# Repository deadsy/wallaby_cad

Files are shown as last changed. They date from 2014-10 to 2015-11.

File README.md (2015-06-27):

# wallaby_cad

CAD files for the Wallaby Engine

## Scaling

These CAD files are the size of the original plans.
I wanted a larger engine and so scaled each linear dimension by 1.25

Engine Build = 1.25
Pattern Scaling = (1.25/0.98) = 1.276

Carburetor Build = sqrt(1.25^3) = 1.398
Pattern Scaling = (1.398/0.98) = 1.426

 * Al casting shrinkage = 0.98
 * Fuel volume requirements are a function of engine volume while carburetor delivery capability is a function of bore area.

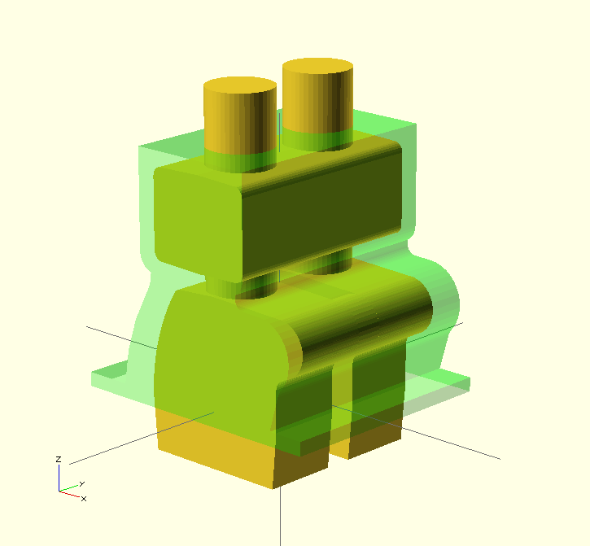
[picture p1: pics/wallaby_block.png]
Wallaby Engine Block with Core


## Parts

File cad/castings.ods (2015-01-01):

Description | CAD | Pattern | Casting | Material | Needed | Made | Notes
Engine Sump | Done | Done | Done | Al | 1 | 2
Engine Block | Done | Done | Done | Al | 1 | 2
Timing Cover | Done | Done | Done | Al | 1 | 2
Cylinder Head | Partial |  |  | Al | 1 | 0
Cylinder Head Cover | Done | Done | Done | Al | 1 | 2
Bearing Cap | Done | Done | Done | Al | 1 | 2 | 3 cut from each casting
Conrod | Done | Done |  | Bronze | 2 | 0
Piston | Done |  |  | Al | 2 | 0
Balance Weight | Done | Done | Partial | Bronze | 2 | 1 | 2 cut from each casting
Valve Rocker Bearing | Done | Done |  | Al | 1 | 0
Oil Pump Body | Done | Done | Partial | Brass | 1 | 0
Flywheel | Done | Done | Done | Brass | 1 | 2
Inlet Stub | Done |  |  | Al | 1 | 0
Carburettor Body |  |  |  | Al | 1 | 0
Float Chamber |  |  |  | Al | 1 | 0

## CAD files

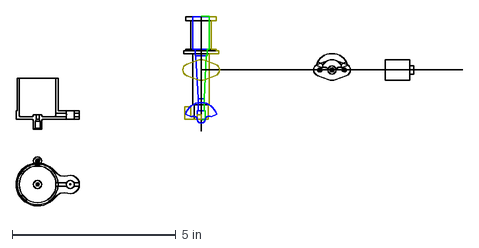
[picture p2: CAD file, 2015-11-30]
cad/carburetor.dxf
13.7 x 5.85 in

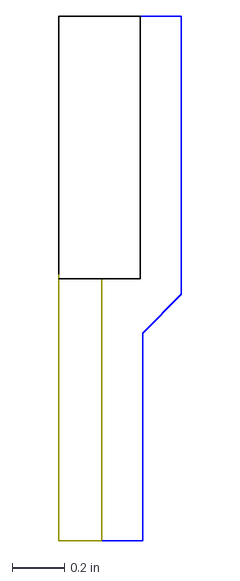
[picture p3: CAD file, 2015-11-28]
cad/sparkplug.dxf
0.469 x 2.00 in

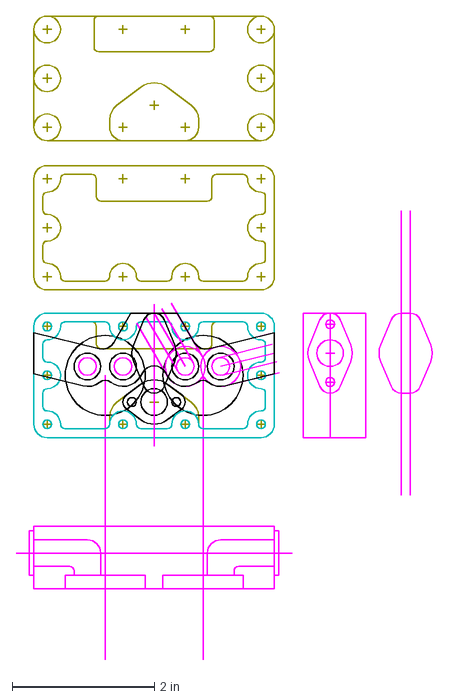
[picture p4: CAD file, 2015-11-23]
cad/head_cover.dxf
5.86 x 9.05 in

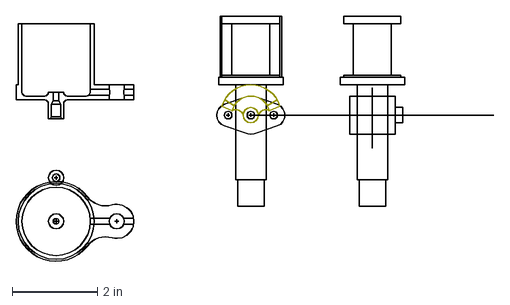
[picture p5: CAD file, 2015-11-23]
cad/carburetor_scaled.dxf
11.2 x 5.83 in

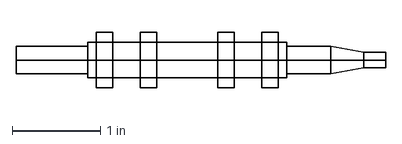
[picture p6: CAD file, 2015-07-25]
cad/camshaft.dxf
4.19 x 0.625 in

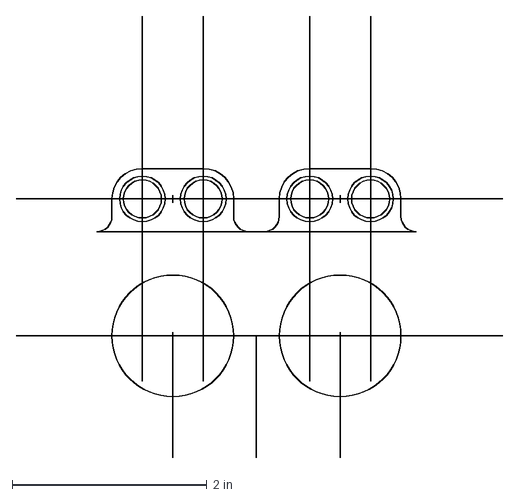
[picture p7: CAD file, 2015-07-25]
cad/bore_spacing_scaled.dxf
5.00 x 4.53 in

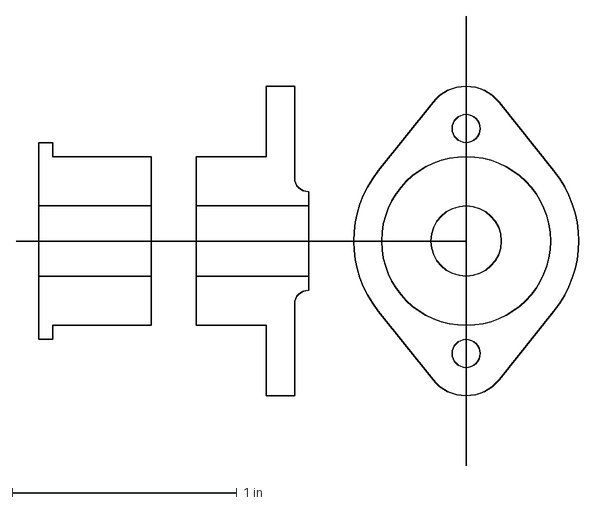
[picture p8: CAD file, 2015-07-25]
cad/cam_bearings.dxf
2.54 x 2.00 in

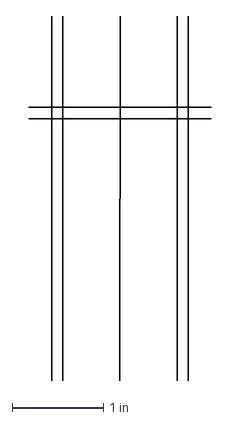
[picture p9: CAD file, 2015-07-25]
cad/cylinder_liner.dxf
2.00 x 4.00 in

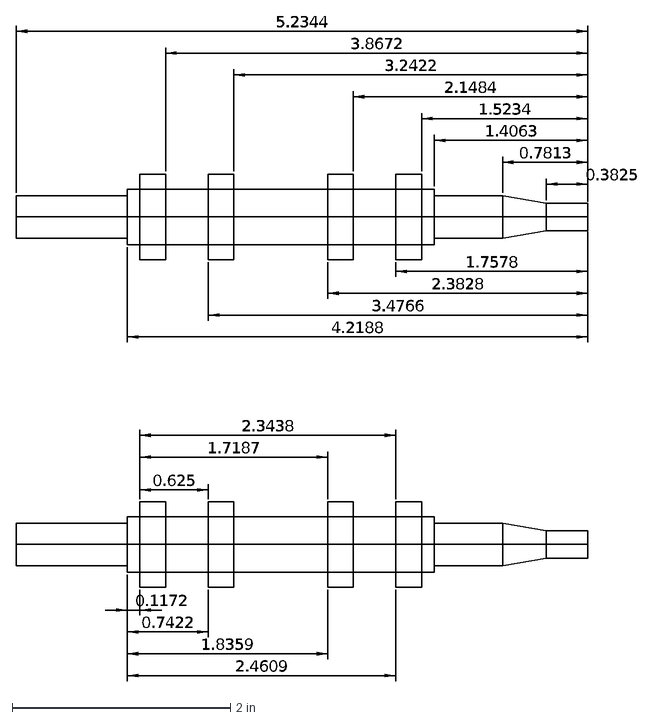
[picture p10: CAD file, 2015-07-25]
cad/camshaft_scaled.dxf
0.7813
1.4063
1.5234
2.1484
3.2422
3.8672
5.2344
1.7578
2.3828
3.4766
4.2188
0.1172
0.7422
1.8359
2.4609
0.625
1.7187
2.3438
0.3825

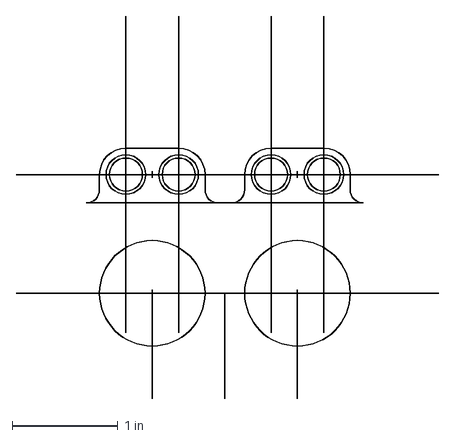
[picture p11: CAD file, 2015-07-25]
cad/bore_spacing.dxf
4.00 x 3.62 in

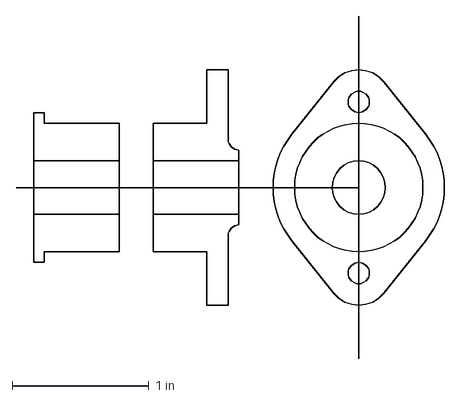
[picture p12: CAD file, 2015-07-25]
cad/cam_bearings_scaled.dxf
3.17 x 2.50 in

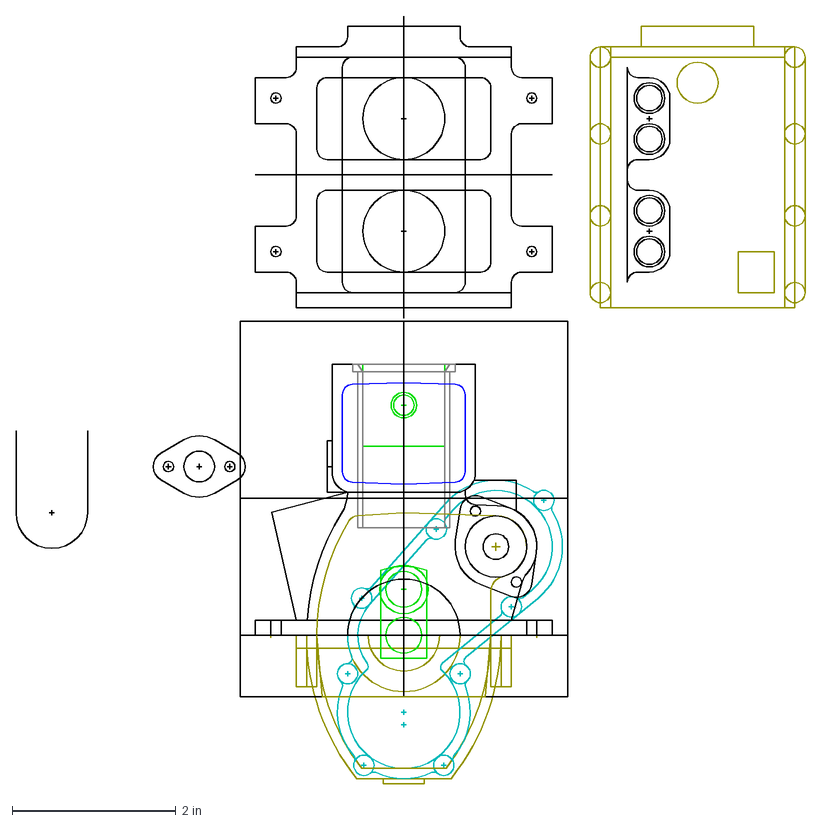
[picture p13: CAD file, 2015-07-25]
cad/engine_body.dxf
9.64 x 9.38 in

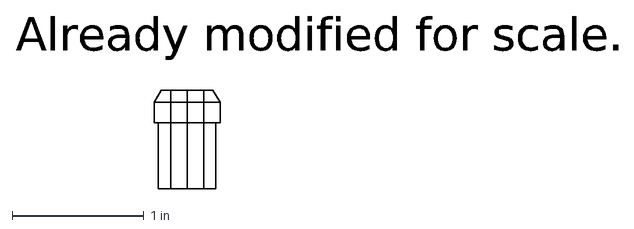
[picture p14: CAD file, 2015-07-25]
cad/lifters.dxf
Already modified for scale.

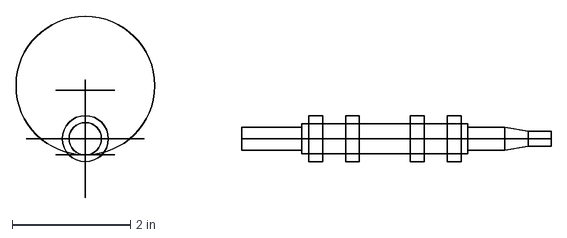
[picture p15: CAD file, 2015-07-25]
cad/cam_jig.dxf
9.06 x 3.07 in

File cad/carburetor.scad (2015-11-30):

//------------------------------------------------------------------


//------------------------------------------------------------------

casting = false;

//------------------------------------------------------------------
// tweak a length to avoid rendering issues when diff-ed surfaces
// align with each other.

tweak = 0.001;

//------------------------------------------------------------------
// control the number of facets on cylinders

_accuracy = 0.001;
function fn(r) = 180 / acos(1 - (_accuracy / r));

//------------------------------------------------------------------

module carb_body() {
  rotate_extrude($fn = 64)
  import(file = "carburetor.dxf", layer = "body_profile",  $fn = fn(0.1));
}

module carb_body_bore() {
  rotate_extrude($fn = 64)
  import(file = "carburetor.dxf", layer = "body_bore_profile",  $fn = fn(0.1));
}

hh_r = (1/16)/2;
hh_l = (1/2);
hh_pcr = (13/16)/2;
head_z = 3 + (1/8);

module head_holes() {
  for (theta = [30,90,150,210,270,330]) {
    rotate([0,0,theta]) {
      translate([hh_pcr,0,-hh_l/2 + head_z]) {
        cylinder(h = hh_l, r = hh_r, $fn = fn(hh_r));
      }
    }
  }
}

//------------------------------------------------------------------

tb_w = 3/4;

module throttle_body() {
  rotate([90,0,0]) {
    translate([0,0,-tb_w/2]) {
      linear_extrude(height = tb_w)
      import(file = "carburetor.dxf", layer = "throttle_body_profile",  $fn = fn(0.1));
    }
  }
}

tbb_r = (1/2)/2;
tbb_l = 5/8;
tbb_z = 1 + (1/2);

module tb_bore() {
  translate([0,tb_w/2 + tweak,tbb_z]) {
    rotate([90,0,0]) {
      cylinder(h = tbb_l, r = tbb_r, $fn = fn(tbb_r));
    }
  }
}

tbh_r = (1/8)/2;
tbh_l = 2;

module tb_holes() {
  for (ofs = [-(3/8), 0, (3/8)]) {
    translate([ofs,0,tbb_z]) {
      rotate([90,0,0]) {
        translate([0,0,-tbh_l/2]) {
          cylinder(h = tbh_l, r = tbh_r, $fn = fn(tbh_r));
        }
      }
    }
  }
}

tp_h = 1;

module throttle_plate() {
  translate([0,-tb_w/2 + tweak,tbb_z]) {
    rotate([90,0,0]) {
      intersection() {
        translate([0,0,-tp_h/2]) {
          linear_extrude(height=tp_h)
          import(file = "carburetor.dxf", layer = "throttle_plate_pattern",  $fn = fn(0.1));
        }
        rotate_extrude($fn = 64)
        import(file = "carburetor.dxf", layer = "throttle_plate_profile",  $fn = fn(0.1));
      }
    }
  }
}

//------------------------------------------------------------------
// airholes

aht_r = (5/32)/2;
aht_l = 2;
aht_z = (3.125 - (7/16));

module air_holes_top() {
  translate([0,0,aht_z]) {
    for (theta= [0,60,120]) {
      rotate([0,0,theta]) {
        rotate([90,0,0]) {
          translate([0,0,-aht_l/2]) {
            cylinder(h = aht_l, r = aht_r, $fn = fn(aht_r));
          }
        }
      }
    }
  }
}

ahb_r = (1/8)/2;
ahb_l = 2;
ahb_z = (5/16);

module air_holes_bottom() {
  translate([0,0,ahb_z]) {
    for (theta= [0,90]) {
      rotate([0,0,theta]) {
        rotate([90,0,0]) {
          translate([0,0,-ahb_l/2]) {
            cylinder(h = ahb_l, r = ahb_r, $fn = fn(ahb_r));
          }
        }
      }
    }
  }
}

//------------------------------------------------------------------

module base_add() {
  carb_body();
  throttle_body();
  throttle_plate();
}

module base_sub() {
  if (casting) {
  } else {
    carb_body_bore();
    air_holes_top();
    air_holes_bottom();
    tb_bore();
    tb_holes();
    head_holes();
  }
}

module base_model() {
  difference() {
    base_add();
    base_sub();
  }
}

//------------------------------------------------------------------

module model() {
  base_model();
}

model();

//------------------------------------------------------------------

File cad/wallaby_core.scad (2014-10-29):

//------------------------------------------------------------------
/*

Wallaby Engine Block Core

*/
//------------------------------------------------------------------
// scaling

_desired_scale = 1.25;
_al_shrink = 0.98;
_scale = _desired_scale / _al_shrink;

//------------------------------------------------------------------
// control the number of facets on cylinders

_accuracy = 0.001;
function fn(r) = 180 / acos(1 - (_accuracy / r));

//------------------------------------------------------------------
// cylinder cores

// unscaled sizes: core = 0.875, cylinder bore = 1.000, liner bore = 1.125
// scaled sizes: core = 1.125, cylinder bore = 1.25, liner bore = 1.406
// So: In the scaled engine we have core size that matches a standard dowel and > 1/4"
// of machining tolerance on the liner bore diameter.

cylinder_d = (1 + (1/8)) / _scale; // diameter
cylinder_h = (3 + (5/16)); // height
core_print_h = 3/4;
c2c_d = (1 + (3/8));

cylinder_r = cylinder_d / 2.0;

module cylinder_core(d) {
	translate([0, d, 0]) {
		cylinder(h = cylinder_h + core_print_h, r = cylinder_r, $fn = fn(cylinder_r));
	}
}

module cylinder_cores() {
	cylinder_core(-c2c_d / 2.0);
	cylinder_core(c2c_d / 2.0);
}

//------------------------------------------------------------------
// camshaft core

camshaft_d = (3/4); // diameter
camshaft_l = 2 + (3/8); // length
camshaft_dx = (1 + (1/8)); // x-displacement
camshaft_dz = 1.084; // z-displacement

camshaft_r = camshaft_d / 2.0;

module camshaft_core() {
	translate([camshaft_dx, 0, camshaft_dz]) {
		rotate([90, 0, 0]) {
			cylinder(h = camshaft_l, r = camshaft_r, center = true, $fn = fn(camshaft_r));
		}
	}
}

//------------------------------------------------------------------
// water jacket

wj_sy = 2 + (7/8);

module water_jacket_core() {
    rotate([90,0,0])
    linear_extrude(height = wj_sy, center = true)
    import(file = "engine_body.dxf", layer = "water_jacket", $fn = fn(0.125));
}

//------------------------------------------------------------------
// body outline

body_l = 3 + (1/8);

module body_outline() {
	 color([0,1,0,0.3])
    rotate([90,0,0])
    linear_extrude(height = body_l, center = true)
    import(file = "engine_body_outline.dxf", $fn = fn(0.25));
}

//------------------------------------------------------------------
// lower cores

lower_sy = 1;

module lower_core(d) {
    translate([0, d, 0])
    rotate([90,0,0])
    linear_extrude(height = lower_sy, center = true)
    import(file = "engine_body.dxf", layer = "lower_core", $fn = fn(8.0));
}

module lower_cores() {
	lower_core(-c2c_d / 2);
	lower_core(c2c_d / 2);
}

//------------------------------------------------------------------

cylinder_cores();
lower_cores();
water_jacket_core();
camshaft_core();
body_outline();

//------------------------------------------------------------------

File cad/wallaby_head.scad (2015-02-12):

//------------------------------------------------------------------
/*

Wallaby Cylinder Head

*/
//------------------------------------------------------------------
// scaling

_desired_scale = 1.25;
_al_shrink = 0.98;
_scale = _desired_scale / _al_shrink;

//------------------------------------------------------------------
// tweak a height to avoid rendering issues when diff-ed surfaces
// align with each other.

tweak = 0.001;

//------------------------------------------------------------------
// control the number of facets on cylinders

_accuracy = 0.001;
function fn(r) = 180 / acos(1 - (_accuracy / r));

//------------------------------------------------------------------

cylinder_h = 3/16;
cylinder_d = 1 + (1/8);
cylinder_wall = 3/16;
cylinder_r = cylinder_d / 2;

dome_r = cylinder_wall + cylinder_r;
dome_h = cylinder_wall + cylinder_h;
dome_draft = [1.04,1.04];

c2c_d = (1 + (3/8));

module cylinder_dome(d) {
  translate([d,0,dome_h - head_h_lower]) {
    rotate([0,180,0]) {
      linear_extrude(height = dome_h, scale = dome_draft) 
      circle(r = dome_r, $fn = fn(dome_r));
    }
  }
}

module cylinder_domes() {
  cylinder_dome(-c2c_d/2);
  cylinder_dome(c2c_d/2);
}

//------------------------------------------------------------------

head_tweak = 1;

module cylinder_head(d) {
  translate([d,0,-head_h_lower - head_tweak]) {
    cylinder(h = cylinder_h + head_tweak, r = cylinder_r, $fn = fn(cylinder_r));
  }
}

module cylinder_heads() {
  cylinder_head(-c2c_d / 2.0);
  cylinder_head(c2c_d / 2.0);
}

//------------------------------------------------------------------
// cylinder head wall

head_w = 1 + (3/4);
head_h_lower = 1/2;
head_h_upper = 3/8;
head_h = head_h_upper + head_h_lower;
head_draft_outer = [1.01,1.01];
head_draft_inner = [0.98,0.98];

module head_outer() {
  translate([0,0,-head_h_lower]) {
    linear_extrude(height = head_h_lower, scale = head_draft_outer)
    import(file = "head_cover.dxf", layer = "head_wall_outer", $fn = fn(0.25));
  }
  translate([0,0,head_h_upper]) {
    rotate([0,180,0]) {
      linear_extrude(height = head_h_upper, scale = head_draft_outer)
      import(file = "head_cover.dxf", layer = "head_wall_outer", $fn = fn(0.25));
    }
  }
}

module head_inner() {
  translate([0,0,head_h_upper]) {
    rotate([0,180,0]) {
      linear_extrude(height = head_h + tweak, scale = head_draft_inner)
      import(file = "head_cover.dxf", layer = "head_wall_inner", $fn = fn(0.25));
    }
  }
}

module head_stud_holes() {
  translate([0,0,-head_h_lower]) {
    linear_extrude(height = head_h + tweak)
    import(file = "head_cover.dxf", layer = "head_wall_holes", $fn = fn(0.25));
  }
}

module head_walls()
{
  difference() {
    head_outer();
    head_inner();
  }
}

//------------------------------------------------------------------
// cylinder head base

base_h = 1/8;

module head_base() {
  translate([0,0,-head_h_lower]) {
    linear_extrude(height = base_h)
    import(file = "head_cover.dxf", layer = "head_wall_outer", $fn = fn(0.25));
  }
}

//------------------------------------------------------------------

valve_d = 1/4;
valve_r = valve_d/2;
valve_y_ofs = 1/8;
valve_wall = 1/8;
v2v_d = 1/2;
valve_draft = [1.1,1.1];

module valve(d) {
  translate([d,valve_y_ofs, head_h_upper]) {
    rotate([180,0,0]) {
      linear_extrude(height = head_h - cylinder_h, scale = valve_draft)
      circle(r = valve_r + valve_wall, $fn = fn(1/4));
    }
  }
}

module valve_set(d) {
  translate([d,0,0]) {
    valve(-v2v_d/2);
    valve(v2v_d/2);
  }
}

module valve_sets() {
    valve_set(-c2c_d/2);
    valve_set(c2c_d/2);
}

module valve_holes() {
  translate([0,0,-head_h_lower]) {
    linear_extrude(height = head_h + tweak)
    import(file = "head_cover.dxf", layer = "valve_holes", $fn = fn(1/8));
  }
}

//------------------------------------------------------------------

sp_hole_d = 21/64;
sp_hole_r = sp_hole_d/2;
sp2sp_d = 1 + (5/8);
sp_hole_h = 3;
sp_theta = 30;
sp_gap = (head_w/2) - ((7/16)/tan(sp_theta));
sp_base = ((7/16)/tan(sp_theta)) - ((5/16)*sin(sp_theta));
sp_y_ofs = -(sp_gap + sp_base);
sp_z_ofs = (sp_base * tan(sp_theta)) - head_h_lower;

module sp_boss(d) {
  translate([d,sp_y_ofs,sp_z_ofs]) {
    rotate([90-sp_theta,0,0]) {
      rotate_extrude($fn = 64)
      import(file = "sparkplug.dxf", layer = "outer");
    }
  }
}

module sp_bosses() {
  intersection() {
    head_outer();
    union() {
	   sp_boss(-sp2sp_d/2);
	   sp_boss(sp2sp_d/2);
    }
  }
}

module sp_hole(d) {
  translate([d,sp_y_ofs,sp_z_ofs]) {
    rotate([90-sp_theta,0,0]) {
      rotate_extrude($fn = 64)
      import(file = "sparkplug.dxf", layer = "inner");
    }
  }
}

module sp_holes() {
	sp_hole(-sp2sp_d/2);
	sp_hole(sp2sp_d/2);
}

//------------------------------------------------------------------

manifold_r = 5/16;
inlet_theta = 30.2564;
exhaust_theta = 270 + 13.9736;
exhaust_x_ofs = (c2c_d/2) + (v2v_d/2);
inlet_x_ofs = (c2c_d/2) - (v2v_d/2);

module manifold_set() {
  translate([exhaust_x_ofs,valve_y_ofs,0]) {
    rotate([-90,0,exhaust_theta]) {
      cylinder(h=2,r=manifold_r, $fn = fn(manifold_r));
    }
  }
  translate([inlet_x_ofs,valve_y_ofs,0]) {
    rotate([-90,0,inlet_theta]) {
      cylinder(h=2,r=manifold_r, $fn = fn(manifold_r));
    }
  }
}

module manifolds() {
  manifold_set();
  mirror([1,0,0]) {
    manifold_set();
  }
}

//------------------------------------------------------------------

module additive() {

  head_walls();
  //head_base();
  cylinder_domes();
  sp_bosses();
  valve_sets();
  manifolds();
}

module subtractive() {
  head_stud_holes();
  cylinder_heads();
  valve_holes();
  sp_holes();
}

//------------------------------------------------------------------

difference() {
  additive();
  subtractive();
}

//------------------------------------------------------------------

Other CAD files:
cad/head_cover_scaled.dxf
cad/piston_scaled.dxf
cad/piston.dxf
cad/inlet_stub.dxf
cad/wallaby_head2.scad
cad/balance_weight.dxf
cad/balance_weight_scaled.dxf
cad/bearing_cap.dxf
cad/bearing_cap_scaled.dxf
cad/conrod.dxf
cad/conrod_scaled.dxf
cad/engine_body_outline.dxf
cad/engine_body_scaled.dxf
cad/flywheel.dxf
cad/flywheel_scaled.dxf
cad/inlet_stub_scaled.dxf
cad/oil_pump_housing.dxf
cad/oil_pump_housing_scaled.dxf
cad/rocker_bearing.dxf
cad/rocker_bearing_scaled.dxf
cad/sump.dxf
cad/sump_scaled.dxf
cad/timing_cover.dxf
cad/timing_cover_scaled.dxf
cad/wallaby_head3.scad

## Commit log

2014-10-22 Initial files added.
    [body_underside.dxf, engine_body.dxf, engine_body_scaled.dxf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]
2014-10-22 Added scad file for engine block core.
    [wallaby_core.scad]
2014-10-23 Moving the core model towards real dimensions.
    [engine_body.dxf, wallaby_core.scad]
2014-10-24 Added facet control to cylinder rendering.
    [wallaby_core.scad]
2014-10-24 Added engine outline and lower core.
    [engine_body_outline.dxf, lower_core.dxf, wallaby_core.scad]
2014-10-25 Tweaks to the lower body cores.
    [wallaby_core.scad]
2014-10-25 Tweaking cylinder core diameter to get a standard dowel size.
    [wallaby_core.scad]
2014-10-27 Added core prints.
    [wallaby_core.scad]
2014-10-29 Tuning the engine block core.
    [engine_body.dxf, lower_core.dxf, wallaby_core.scad]
2014-10-29 More tweaks to the engine body core.
    [engine_body.dxf, wallaby_core.scad]
2014-10-30 Added the block outlines within which the engine block core will be made.
    [engine_body.dxf, engine_body_scaled.dxf]
2014-11-05 Added list of castings.
    [castings.ods, engine_body_scaled.dxf]
2014-11-05 Added flywheel drawing.
    [flywheel.dxf]
2014-11-06 Created the CAD drawings for more parts.
    [bearing_cap.dxf, castings.ods, oil_pump_housing.dxf]
2014-11-06 Fixed the draft on the lower engine block core.
    [engine_body.dxf]
2014-11-07 Added a drawing for the crankshaft balance weights.
    [balance_weight.dxf, castings.ods]
2014-11-08 Added CAD for conrod.
    [conrod.dxf]
2014-11-09 Pattern/casting status updates.
    [balance_weight_scaled.dxf, castings.ods, flywheel_scaled.dxf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]
2014-11-09 Working on bearing caps.
    [bearing_cap_scaled.dxf, castings.ods]
2014-11-10 Updated castings status.
    [castings.ods]
2014-11-11 Fixed up the head cover. Completed the conrod.
    [castings.ods, conrod_scaled.dxf, head_cover.dxf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]
2014-11-11 Added rocker bearings.
    [castings.ods, rocker_bearing.dxf, rocker_bearing_scaled.dxf]
2014-11-12 Working on the cylider head.
    [head_cover.dxf]
2014-11-12 Working on scad version of head.
    [head_cover.dxf, wallaby_head.scad]
2014-11-13 Added cylinder heads to the 3D head.
    [head_cover.dxf, head_cover_scaled.dxf, wallaby_head.scad]
2014-11-18 Added inlet stub.
    [castings.ods, inlet_stub.dxf, inlet_stub_scaled.dxf]
2014-11-19 Added draft to the cylinder head walls.
    [wallaby_head.scad]
2014-11-20 Added the base of the head and the cylinder domes.
    [wallaby_head.scad]
2014-11-20 Working on valve bosses.
    [head_cover.dxf, wallaby_head.scad]
2014-11-22 Added draft to valve bosses. Added sparkplug holes.
    [wallaby_head.scad]
2014-11-22 Added sparkplug bosses.
    [sparkplug.dxf, wallaby_head.scad]
2014-11-27 Working on the head.
    [castings.ods, head_cover.dxf, wallaby_head.scad]
2014-12-09 Status updates.
    [castings.ods]
2014-12-10 Added piston cad.
    [castings.ods, piston.dxf, piston_scaled.dxf]
2014-12-14 minor cleanups
    [body_underside.dxf, piston.dxf, piston_scaled.dxf]
2014-12-22 Updated status.
    [castings.ods]
2015-01-01 Casting status update.
    [castings.ods]
2015-02-12 Adding manifolds to the head.
    [head_cover.dxf, wallaby_head.scad]
2015-06-26 Added some carburetor drawings.
    [carburetor.dxf, head_cover.dxf, head_cover_scaled.dxf]
2015-06-27 Added carburetor body.
    [carburetor.dxf]
2015-06-27 Added carburetor scaling.
    [carburetor_scaled.dxf]
2015-11-23 Added a no draft version of the cylinder head suitable for investment casting.
    [carburetor_scaled.dxf, head_cover.dxf, wallaby_head2.scad]
2015-11-27 Added manifolds.
    [wallaby_head2.scad]
2015-11-28 Added sparkplug countersinks and machining allowances.
    [sparkplug.dxf, wallaby_head2.scad]
2015-11-29 WIP. openscad model of carburetor.
    [carburetor.dxf, carburetor.scad, wallaby_head2.scad]
2015-11-30 Added more holes and the throttle plate.
    [carburetor.dxf, carburetor.scad]
2016-01-30 Third times a charm.
    [wallaby_head3.scad]
2016-01-30 Added head wall code.
    [wallaby_head3.scad]
2016-02-02 Adding more features.
    [wallaby_head3.scad]
2016-02-03 Added sparkplug boss/hole/counterbore.
    [wallaby_head3.scad]
2016-02-03 Added exhaust bosses.
    [wallaby_head3.scad]
2016-02-04 Finished the exhaust bosses.
    [wallaby_head3.scad]
2016-02-05 Added casting allowances.
    [wallaby_head3.scad]
2016-02-06 Simplified rounded/filleted functions.
    [wallaby_head3.scad]
2016-07-25 Added a recess for the wax sprue.
    [wallaby_head3.scad]
2016-07-25 Added al shrinkage.
    [wallaby_head3.scad]
